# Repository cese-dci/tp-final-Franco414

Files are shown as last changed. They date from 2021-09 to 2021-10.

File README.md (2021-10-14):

## Trabajo práctico final de la asignatura DCI ##
Este repositorio contiene el trabajo práctico final para la asignatura de Diseño de Circuitos Impresos de la carrera de posgrado de FIUBA.

* Autor: Geronimo, Franco Ezequiel
* Título corto del trabajo:  Replica Modulo Driver 16-Ch PWM con PCA9685
* Descripción:  El presente trabajo consiste en elaborar un nuevo diseño para el módulo Adafruit controlador de 16 canales PWM/Servos mediante I2C con el integrado PCA9685.
  
## Imagenes de la PCB ##

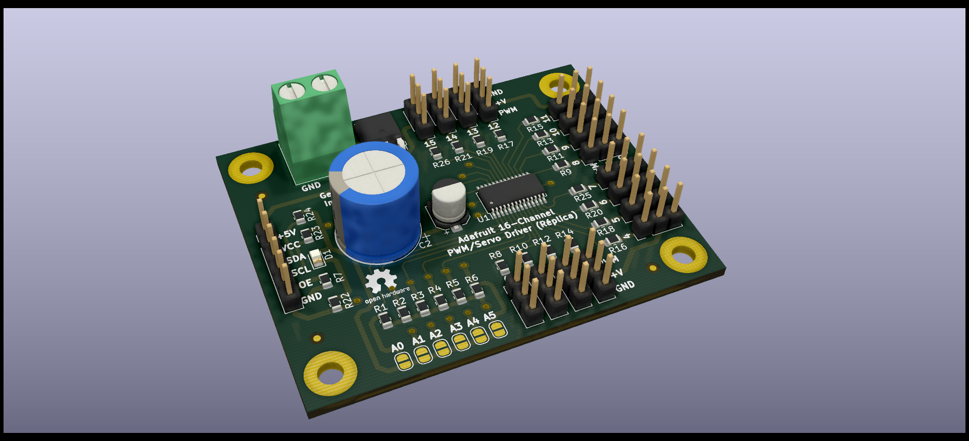
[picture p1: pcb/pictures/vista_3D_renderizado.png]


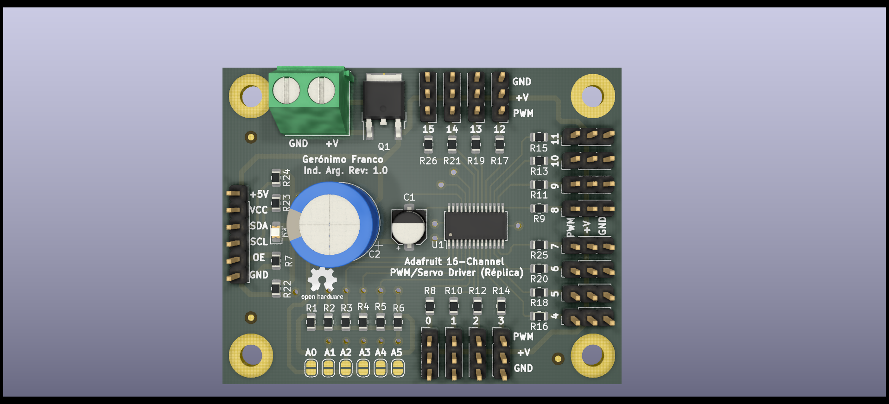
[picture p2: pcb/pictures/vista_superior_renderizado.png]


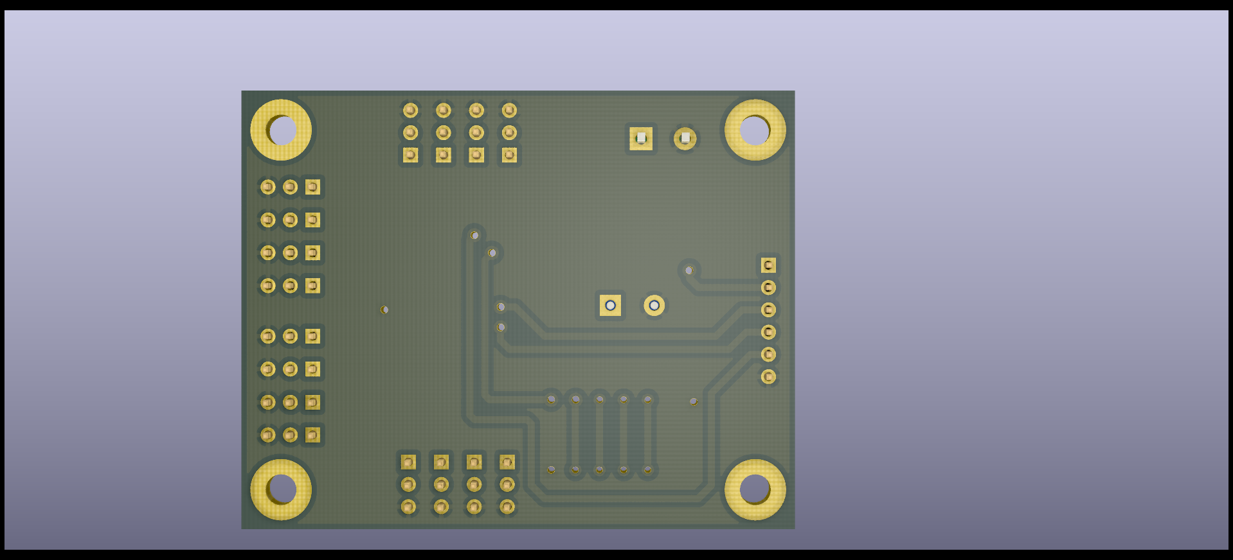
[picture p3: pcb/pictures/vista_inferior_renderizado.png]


## Licencia de este trabajo ##
Esta obra está bajo una Licencia Creative Commons Atribución 4.0 Internacional. 2021

## Estructura del TP FINAL ##

Se propone y se pide utilizar la siguiente estructura.

* doc: Toda la información sobre el circuito, principalmente de autoría o procesamiento propio. Por ejemplo:
  * Notas de ingeniería propias.
  * Notas de aplicación propias.
  * Estudios previos, estado del arte, resumen de las investigaciones.
  * Notas con cálculos.
  * Dibujos adicionales.
  * Fotos de los prototipos.
  * Presupuestos, cotizaciones.
* info: Toda la iformación recolectada, principalmente de terceros, como por ejemplo:
  * Hojas de datos.
  * Notas de aplicación.
  * Info de productos comerciales.
  * Info en internet.
* pcb: Archivos de diseño esquemático y pcb.

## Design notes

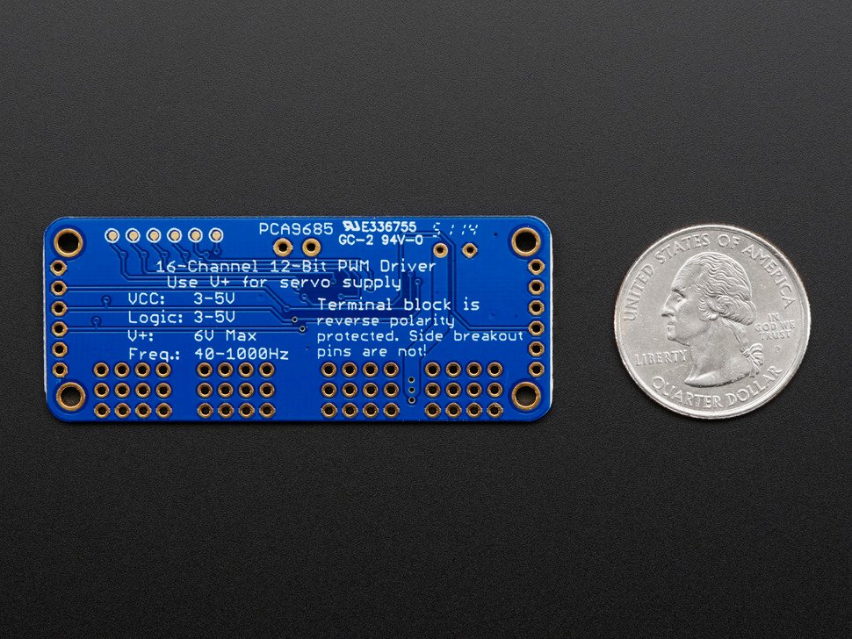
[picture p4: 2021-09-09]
doc/propuesta/Imagenes de la placa/Vista inferior 1.jpg

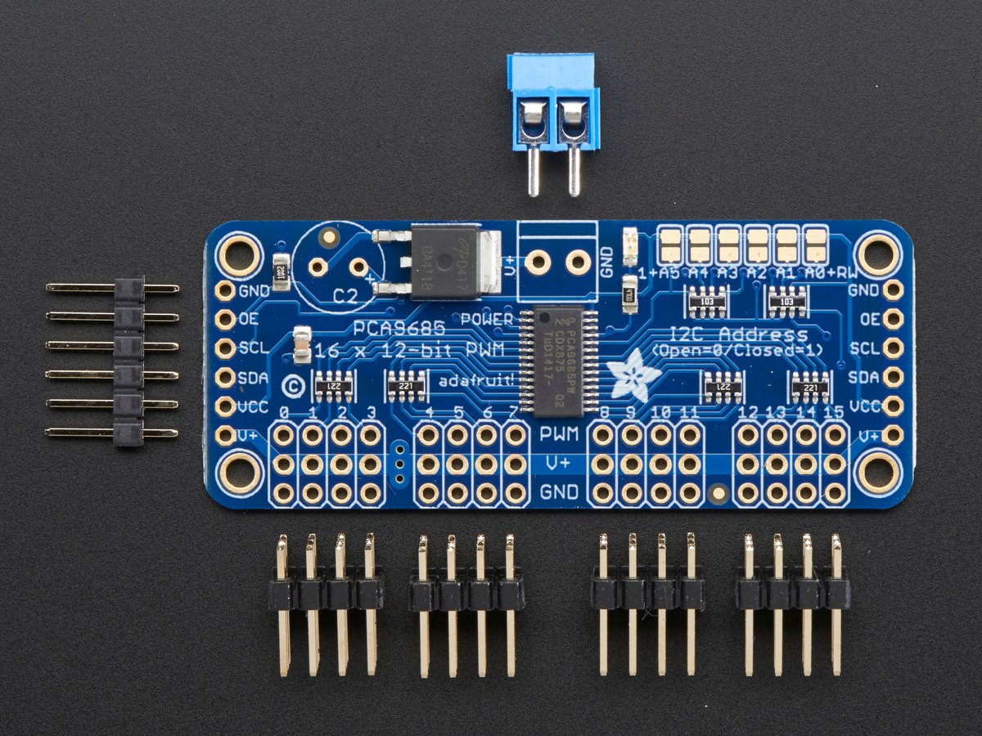
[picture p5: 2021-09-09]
doc/propuesta/Imagenes de la placa/Vista superior 1.jpg

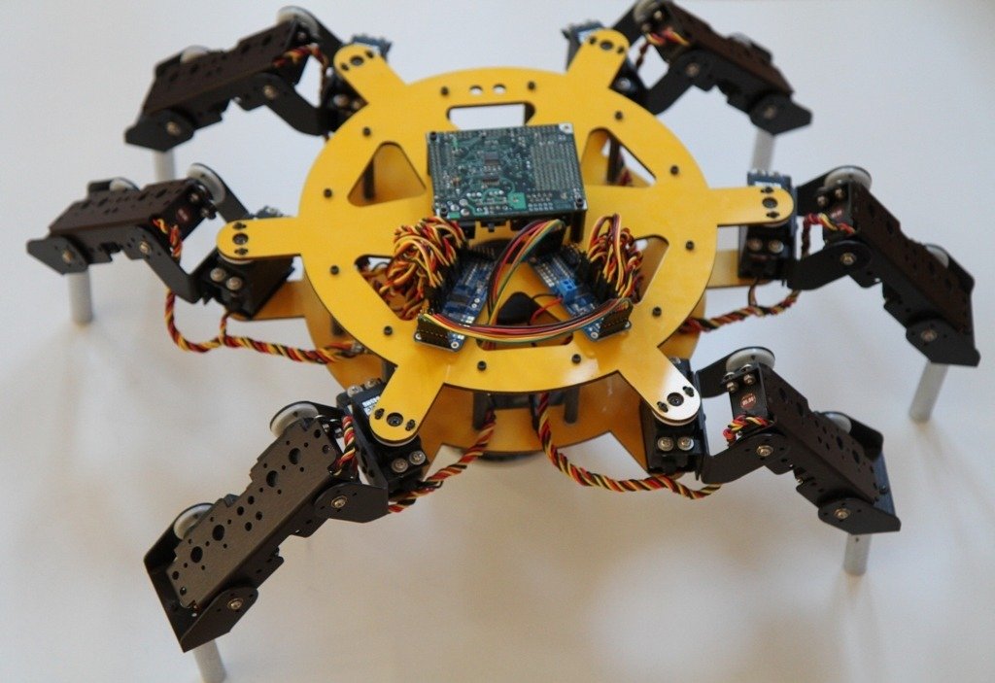
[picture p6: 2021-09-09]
doc/propuesta/Imagenes de la placa/Uso del módulo 2.jpg

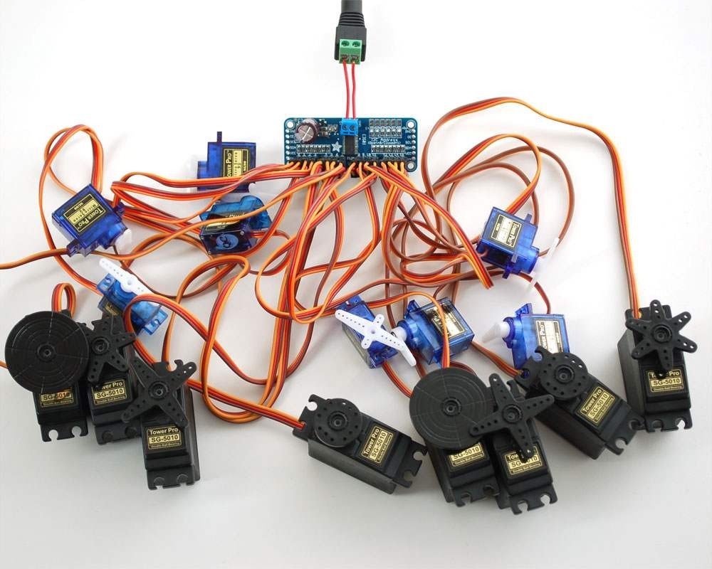
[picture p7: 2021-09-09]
doc/propuesta/Imagenes de la placa/Uso del módulo 1.jpg

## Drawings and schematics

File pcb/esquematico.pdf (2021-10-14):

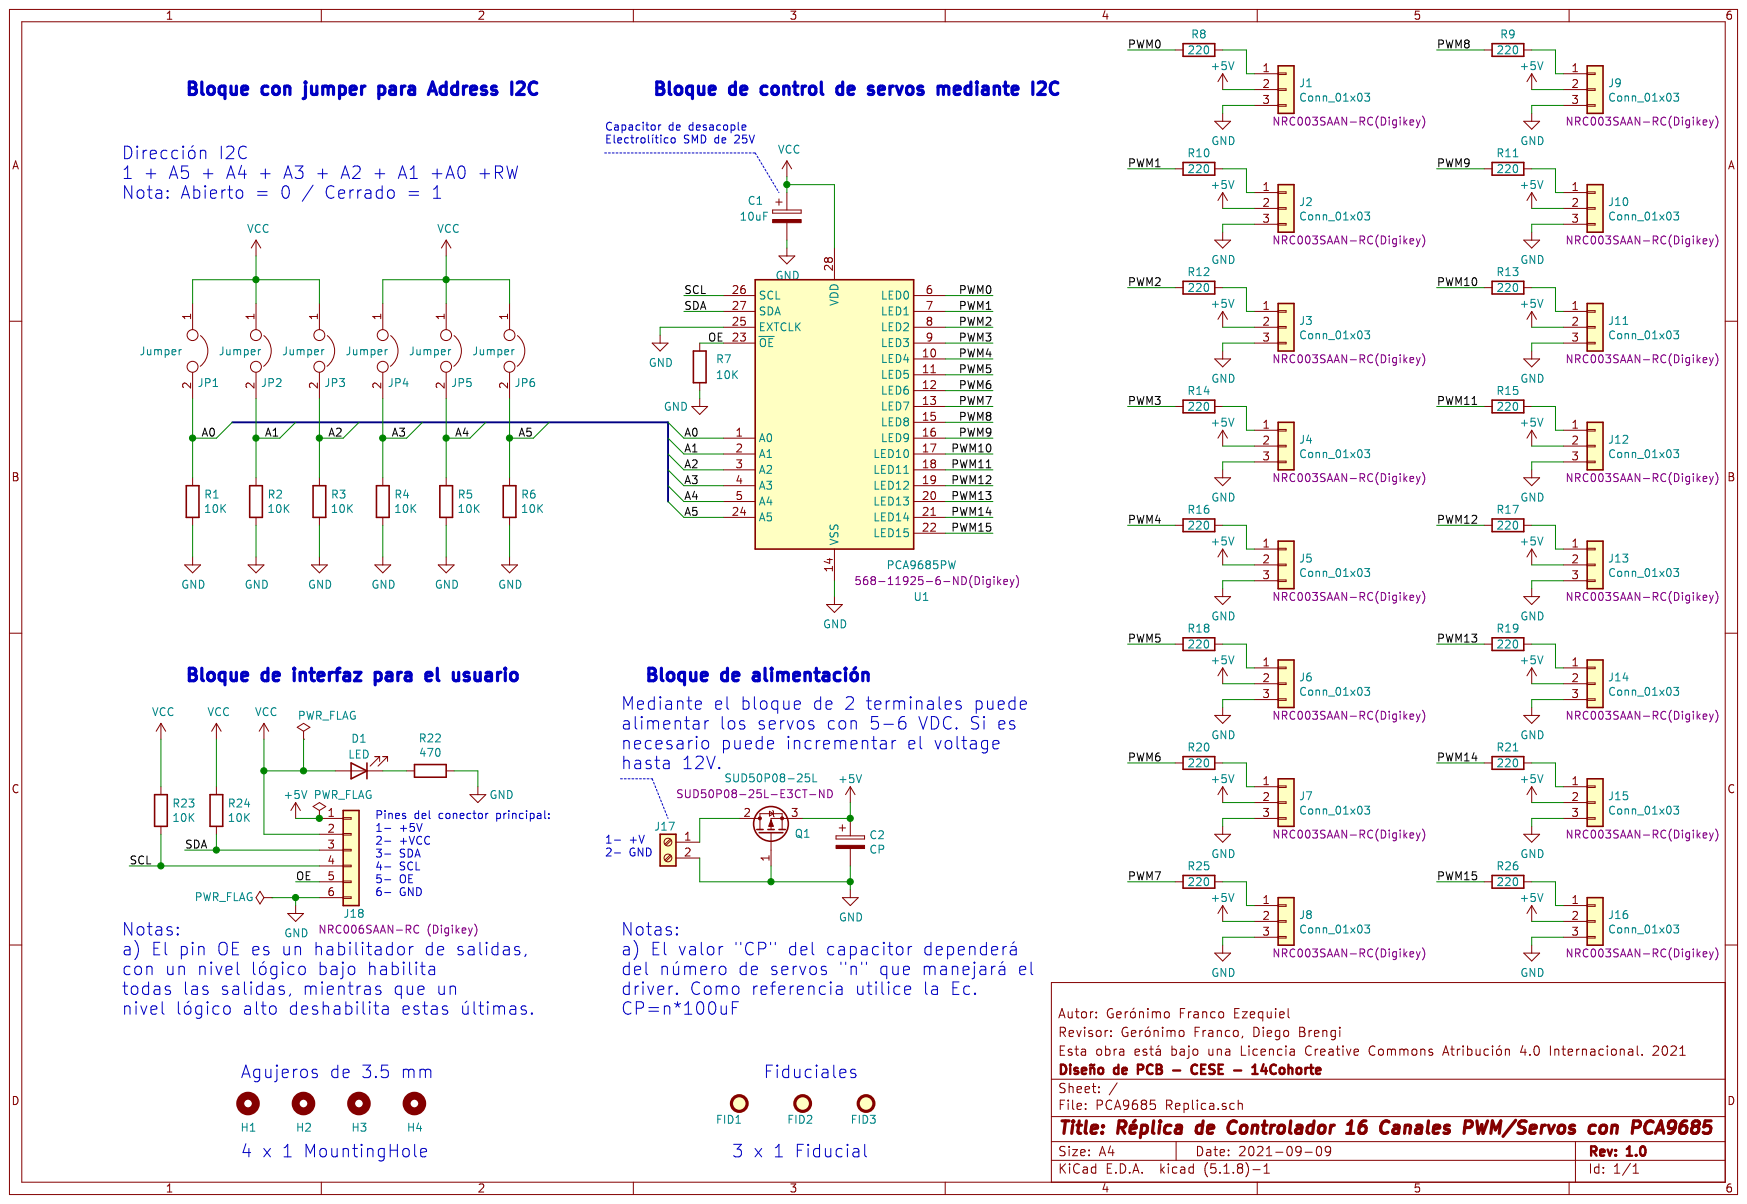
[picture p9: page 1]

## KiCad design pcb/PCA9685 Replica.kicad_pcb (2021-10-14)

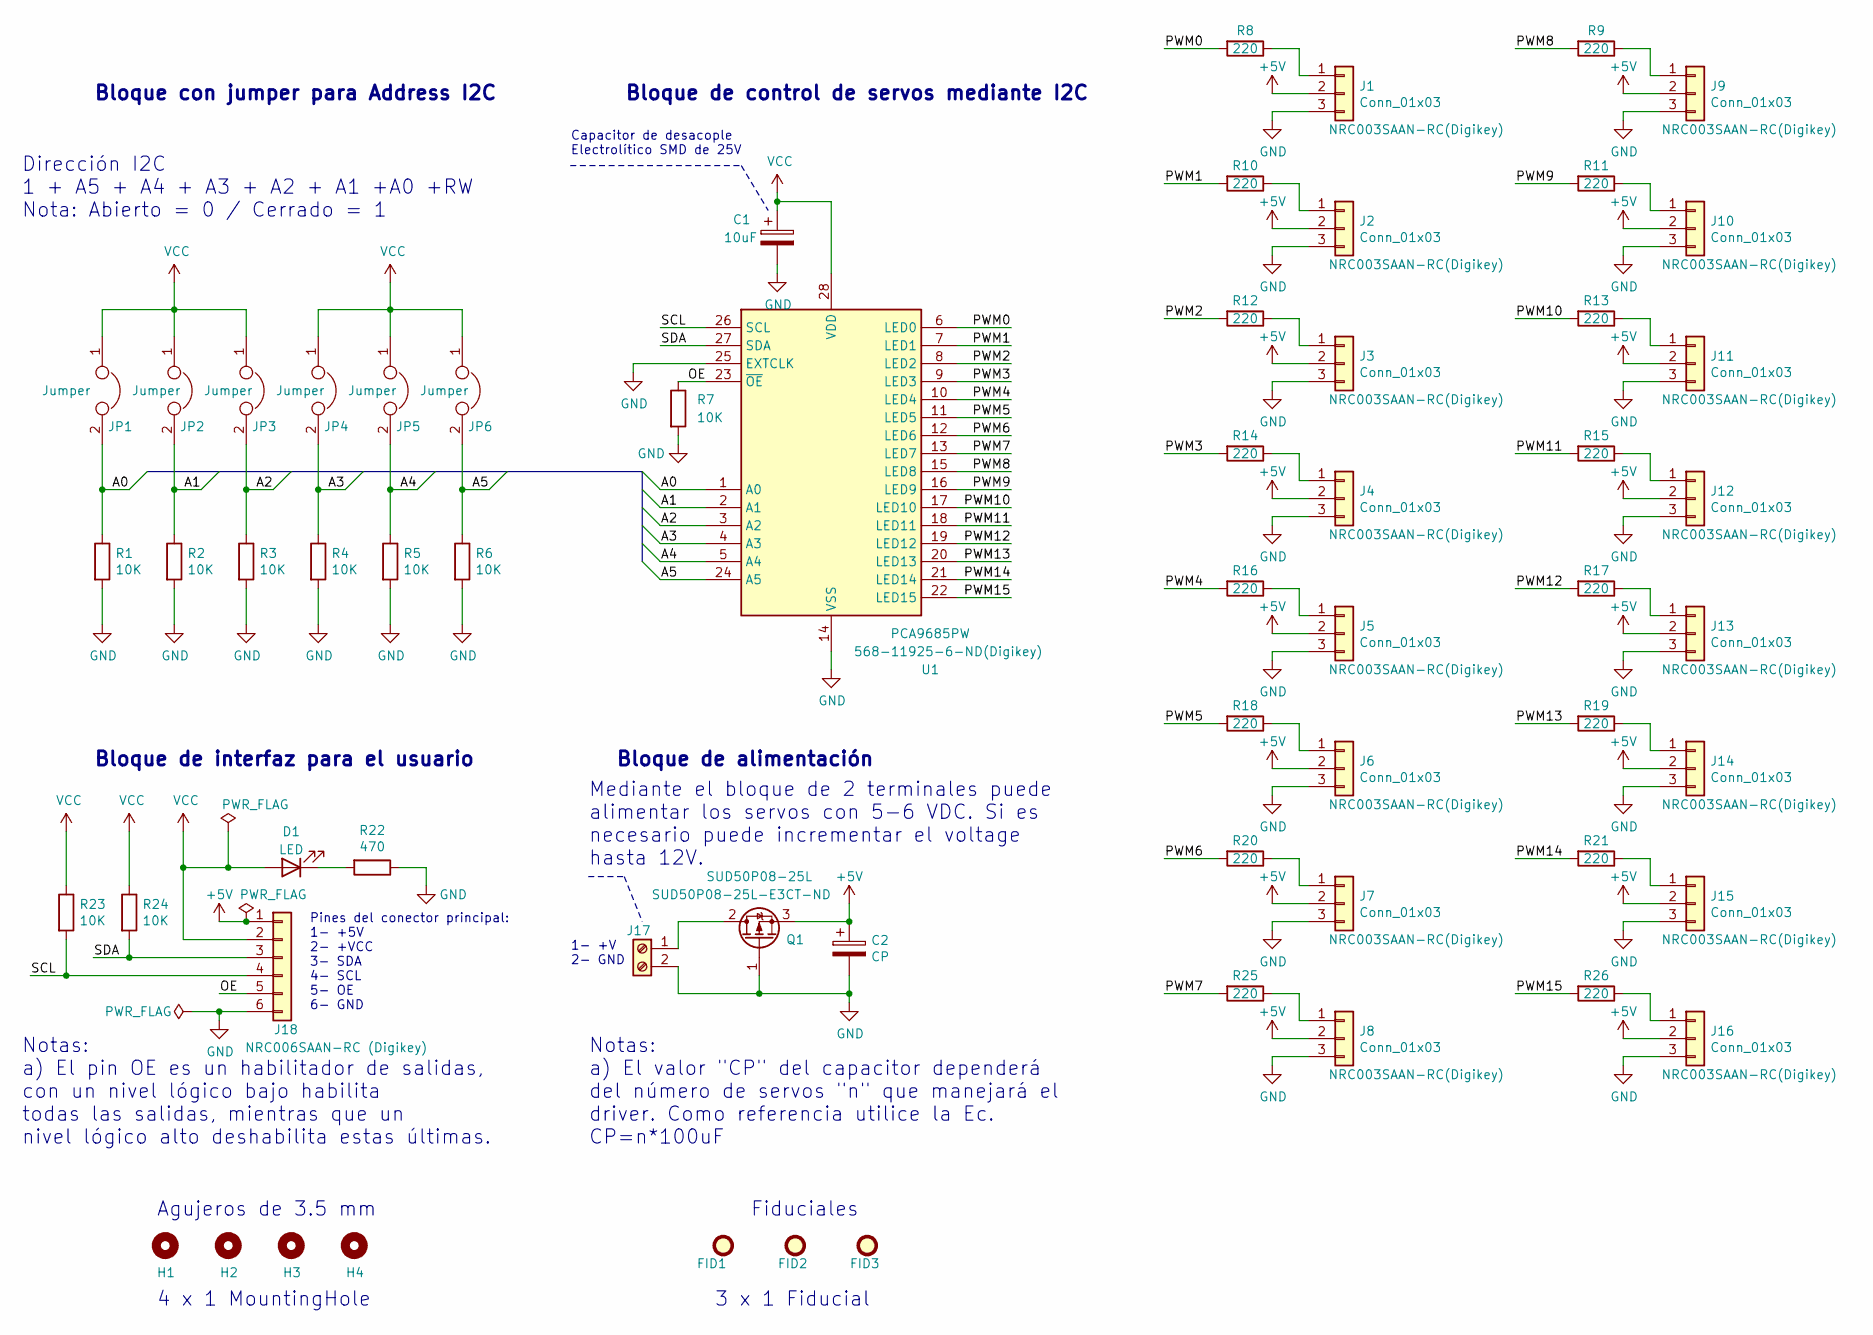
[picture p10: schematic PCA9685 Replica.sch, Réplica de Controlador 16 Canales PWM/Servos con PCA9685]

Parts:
C1: 10uF; CP_Elec_5x5.4
C2: CP; CP_Radial_D12.5mm_P5.00mm
D1: LED; LED_0805_2012Metric_Castellated
FID1, FID2, FID3: Fiducial; Fiducial_1mm_Mask2mm
H1, H2, H3, H4: MountingHole; MountingHole_3.5mm_Pad
J1, J2, J3, J4, J5, J6, J7, J8, J9, J10, J11, J12, J13, J14, J15, J16: Conn_01x03; PinHeader_1x03_P2.54mm_Vertical
J17: Screw_Terminal_01x02; TerminalBlock_Phoenix_MKDS-1,5-2_1x02_P5.00mm_Horizontal
J18: Conn_01x06; PinHeader_1x06_P2.54mm_Vertical
JP1, JP2, JP3, JP4, JP5, JP6: Jumper; SolderJumper-2_P1.3mm_Open_RoundedPad1.0x1.5mm
Q1: SUD50P08-25L; TO-252-2
R1, R2, R3, R4, R5, R6, R7, R23, R24: 10K; R_0805_2012Metric
R8, R9, R10, R11, R12, R13, R14, R15, R16, R17, R18, R19, R20, R21, R25, R26: 220; R_0805_2012Metric
R22: 470; R_0805_2012Metric
U1: PCA9685PW; TSSOP-28_4.4x9.7mm_P0.65mm

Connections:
+5V: C2.1, J1.2, J2.2, J3.2, J4.2, J5.2, J6.2, J7.2, J8.2, J9.2, J10.2, J11.2, J12.2, J13.2, J14.2, J15.2, J16.2, J18.1, Q1.3 (S)
/A0: JP1.2, R1.1, U1.1 (A0)
/A1: JP2.2, R2.1, U1.2 (A1)
/A2: JP3.2, R3.1, U1.3 (A2)
/A3: JP4.2, R4.1, U1.4 (A3)
/A4: JP5.2, R5.1, U1.5 (A4)
/A5: JP6.2, R6.1, U1.24 (A5)
/OE: J18.5, R7.1, U1.23 (~OE)
/PWM0: R8.2, U1.6 (LED0)
/PWM1: R10.2, U1.7 (LED1)
/PWM2: R12.2, U1.8 (LED2)
/PWM3: R14.2, U1.9 (LED3)
/PWM4: R16.2, U1.10 (LED4)
/PWM5: R18.2, U1.11 (LED5)
/PWM6: R20.2, U1.12 (LED6)
/PWM7: R25.2, U1.13 (LED7)
/PWM8: R9.2, U1.15 (LED8)
/PWM9: R11.2, U1.16 (LED9)
/PWM10: R13.2, U1.17 (LED10)
/PWM11: R15.2, U1.18 (LED11)
/PWM12: R17.2, U1.19 (LED12)
/PWM13: R19.2, U1.20 (LED13)
/PWM14: R21.2, U1.21 (LED14)
/PWM15: R26.2, U1.22 (LED15)
/SCL: J18.4, R23.2, U1.26 (SCL)
/SDA: J18.3, R24.2, U1.27 (SDA)
GND: C1.2, C2.2, J1.3, J2.3, J3.3, J4.3, J5.3, J6.3, J7.3, J8.3, J9.3, J10.3, J11.3, J12.3, J13.3, J14.3, J15.3, J16.3, J17.2, J18.6, Q1.1 (G), R1.2, R2.2, R3.2, R4.2, R5.2, R6.2, R7.2, R22.1, U1.14 (VSS), U1.25 (EXTCLK)
unnamed: D1.1 (K), R22.2
unnamed: J1.1, R8.1
unnamed: J2.1, R10.1
unnamed: J3.1, R12.1
unnamed: J4.1, R14.1
unnamed: J5.1, R16.1
unnamed: J6.1, R18.1
unnamed: J7.1, R20.1
unnamed: J8.1, R25.1
unnamed: J9.1, R9.1
unnamed: J10.1, R11.1
unnamed: J11.1, R13.1
unnamed: J12.1, R15.1
unnamed: J13.1, R17.1
unnamed: J14.1, R19.1
unnamed: J15.1, R21.1
unnamed: J16.1, R26.1
unnamed: J17.1, Q1.2 (D)
VCC: C1.1, D1.2 (A), J18.2, JP1.1, JP2.1, JP3.1, JP4.1, JP5.1, JP6.1, R23.1, R24.1, U1.28 (VDD)

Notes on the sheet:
Dirección I2C 1 + A5 + A4 + A3 + A2 + A1 +A0 +RW Nota: Abierto = 0 / Cerrado = 1
Capacitor de desacople Electrolítico SMD de 25V
Notas: a) El pin OE es un habilitador de salidas, con un nivel lógico bajo habilita todas las salidas, mientras que un nivel lógico alto deshabilita estas últimas.
Bloque de interfaz para el usuario
Bloque de alimentación
Bloque de control de servos mediante I2C
Bloque con jumper para Address I2C
Agujeros de 3.5 mm
Fiduciales
Notas: a) El valor "CP" del capacitor dependerá del número de servos "n" que manejará el driver. Como referencia utilice la Ec. CP=n*100uF
Pines del conector principal: 1- +5V 2- +VCC 3- SDA 4- SCL 5- OE 6- GND
4 x 1 MountingHole
3 x 1 Fiducial
Mediante el bloque de 2 terminales puede alimentar los servos con 5-6 VDC. Si es necesario puede incrementar el voltage hasta 12V.
1- +V 2- GND

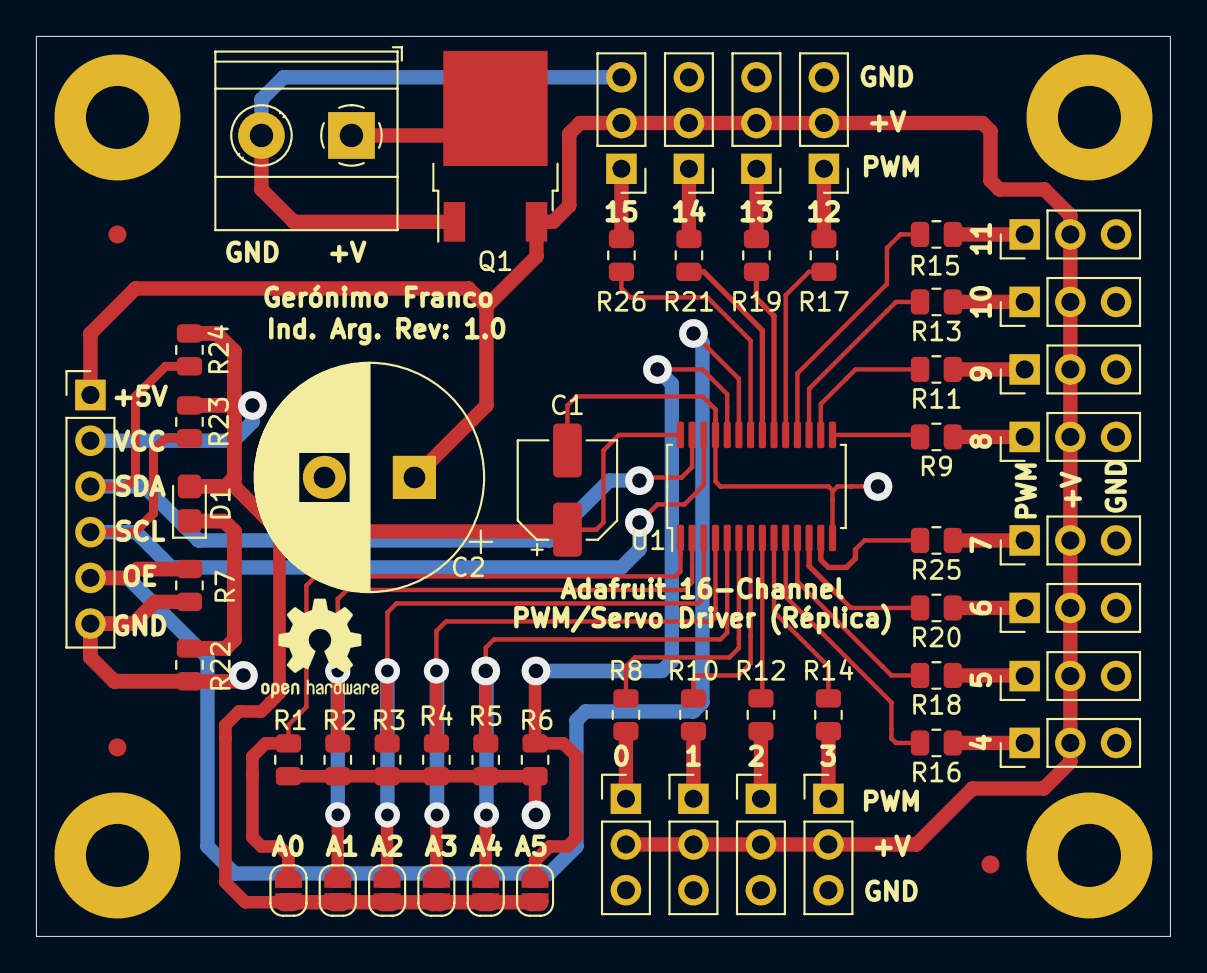
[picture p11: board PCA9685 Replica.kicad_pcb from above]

Board: 2 copper layers, 63.0 x 50.0 mm, 62 parts (0 on the bottom side), 46 nets.

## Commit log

2021-09-09 Add Images and Schematic
2021-09-21 Update pcb folder
    [PCA9685 Replica.kicad_pcb, PCA9685 Replica.sch]
2021-10-14 update project
    [PCA9685 Replica.kicad_pcb, PCA9685 Replica.sch]
2021-10-14 update pcb
    [PCA9685 Replica.kicad_pcb]
